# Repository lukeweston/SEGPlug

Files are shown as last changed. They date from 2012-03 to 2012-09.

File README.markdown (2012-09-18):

**SEGPlug: A single-channel, single-phase, portable, wireless mesh-networked smart energy data acquisition and control appliance**

Design by Luke Weston, 2011-2012
(c) Luke Weston 2011-2012

This hardware design is released to you under the CERN Open Hardware License: http://ohwr.org/cernohl

The Smart Energy Groups SEGPlug is a small, visually unintrusive and portable device which plugs in to a domestic mains power outlet or cable and plugs into a mains-powered
load device. It is (with a small hardware reconfiguration) compatible with worldwide mains power grids, at 110-240VAC and 50-60 Hz. This "Internet of Things" device collects
data from its sensors and data acquisition circuits and transmits this data to a distributed network and ultimately to the Internet and receives commands from a distributed
network and/or the Internet and responds to such commands, for example by switching its onboard power relay on or off. 

SEGPlug acquires the voltage waveform across the load device(s) and the current waveform being consumed by the load device(s) and calculates instantaneous power draw as well
as energy consumption integrated across some period of time, and complex AC power characteristics such as phase angle, reactive power and power factor.

SEGPlug also incorporates a relay allowing the power supply to the load device to be completely switched off and switched on at the command of the device's (very low power)
internal microcontroller.

SEGPlug is powered from the mains power supply which it is plugged into - no additional power supplies or cables are required, everything is integrated into one clean and
simple plug-in cable.

SEGPlug sends and receives data and commands over a wireless radio mesh network, back to a gateway device which bridges the wireless mesh network onto an existing local area
network which is connected to the Internet - over ethernet, and/or standard IEEE 802.11 wireless networking (Wi-Fi), or 3G or similar cellular networks.

To ensure flexible compatibility with worldwide radiofrequency spectrum licensing and regulations and the device's local electromagnetic environment (with respect to spectrum
congestion, interference, or electromagnetic shielding, reflection or attenuation by nearby structures materials in the environment) SEGPlug's radio communications are handled
on a replaceable daughterboard which can be replaced and swapped with different boards or modules employing different communications frequencies or protocols.

My in-house daughterboard design based around the Atmel ATmega128RFA1 radio/microcontroller can be used, thus providing connectivity over IPv6 / 6LoWPAN etc, as well as
ZigBee. Alternatively, a commercial off-the-shelf product such as a Digi/MaxStream XBee module can be used, operating in the 2.4 GHz or 900 MHz spectra with the ZigBee or
DigiMesh protocols (which are, at their lower layers, also built on the 802.15.4 standard.) A daughterboard based around a sub-gigahertz radio device such as the Texas
Instruments CC1101 IC, operating in the 315/433/868/915 MHz bands can also be used, either in the form of a bespoke RF transceiver from us or a COTS device such as the
Seeed RFBee module.

SEGPlug also incorporates a temperature sensor, for measurement of the temperature in the local environment, a light sensor for sensing of the ambient light level, and support
for an optional PIR motion sensor for the detection of motion and an automated response - for example, turning on the room lights and/or reporting a message to the network.

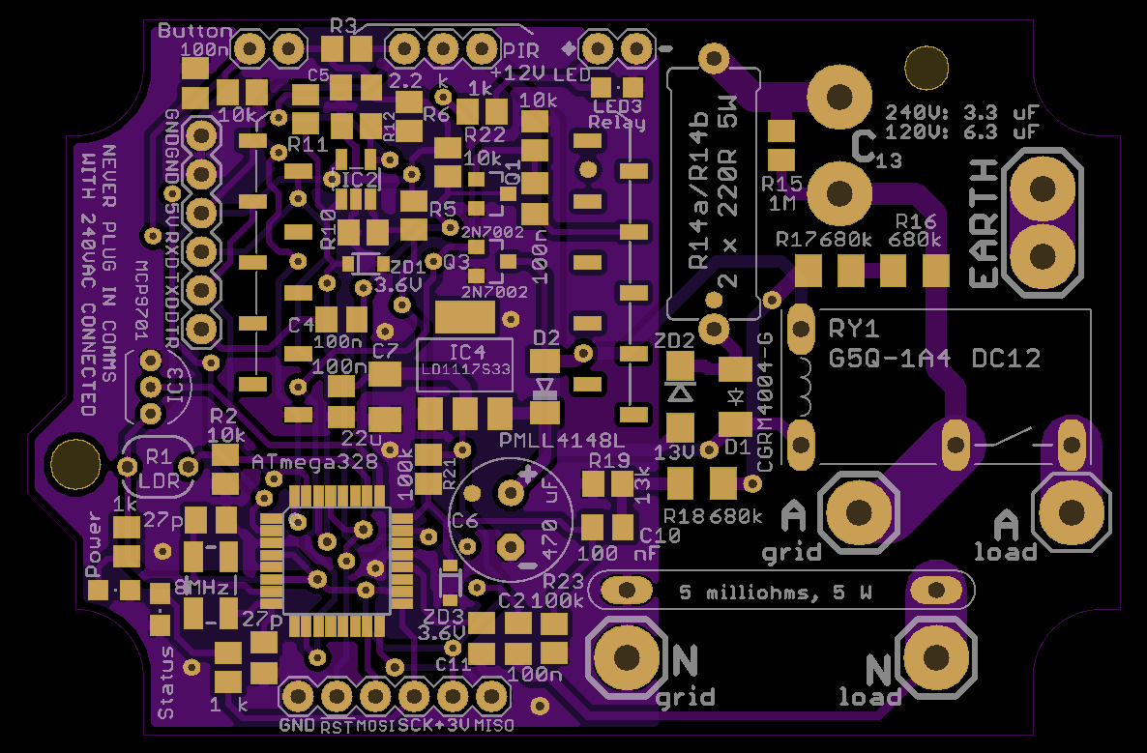
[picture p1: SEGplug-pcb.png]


*Engineering notes for hardware developers, prototype testers, and early adopters:*

This device uses a non-isolated, transformerless mains power supply, with the mains active serving as the local DC ground. What this means is that all parts of the device,
including the microcontroller, XBee module, temperature sensor, and the light and PIR sensors if they're connected, are at mains potential when the device is plugged into the
mains, and all components represent an electric shock hazard. Do not not poke around with this device while it is powered up, with the device not within an earthed enclosure,
or a double-insulated plastic enclosure, unless you know exactly what you're doing.

Also, DO NOT plug the device into any kind of FTDI cable, ISP programmer or any other serial communications interface or programming interface while it is plugged into the
mains. If you do, this will connect your computer's local DC ground to the 240VAC active, and your computer will be destroyed and will probably explode or something, as well
as presenting an electric shock hazard. So don't do it.

It's OK to plug those kinds of interfaces in for programming, obviously, just make damned sure that the mains is unplugged first.

There's nothing "wrong" with a transformerless power supply, though, as long as you understand what it is and what its characteristics are. You'll find very much the same kind
of circuit inside a commercial "kill-a-watt" device, or any similar product. As long as the device does not need to have any cables for data communications out to a computer
or another device, it works absolutely fine. In fact, using this kind of circuit is the only way you're going to keep the size, weight and cost of the device down so that it
is competitive with those kinds of similar commercial products.

The transformerless power supply uses a relatively large cap (2.2 uF) because it needs to supply a relatively large amount of current (about 80 mA) at peak times in order to
reliably run the XBee module (which draws about 50 mA by itself) as well as the relay and AVR without rebooting or crashing the AVR whenever there is a momentary spike in
current draw, whenever the XBee starts transmitting or something like that.

High current means low capacitive reactance which means relatively big capacitor.

Commercial RF modules with relatively high power consumption, such as the Digi/Maxstream "XBee Pro" are unsupported with this system due to power supply constraints in this
design variant and probably won't work reliably, although the standard, lower-power Digi/MaxStream XBee modules are supported. Basically, when using commercial third-party
RF communications modules, the maximum device current consumption during transmission should not exceed 50 mA at 3.3 volts.

It would straightforward to design a safe, optically-isolated plug-in serial cable interface for your computer if something like that was required... but at this point in
time, no such device exists and plugging the unit into your computer (unless the mains is disconnected) is a big no-no.

The maximum power rating of the unit is 10 A at 240 VAC. Do not exceed this limit.

This device is designed for use with 240 VAC mains only. Do not use in a country with a 120 VAC mains supply. It should be possible to change the value of the
capacitive reactance in the mains neutral so that it is OK with 120 VAC operation (which probably means changing the 2.2 uF capacitor to about double its capacitance), but at
the present time this has not been tested and is not supported at all.

The control pushbutton must be rated for mains use. If there is not sufficient electrical isolation between the switch contacts and the plastic switch actuator, an electric
shock hazard may exist during use of the button.

In order to prevent electric shock, fire, explosion, death, etc, careful quality control is required if you're assembling this unit from a kit yourself. Solder everything
carefully, and check that you've got the components oriented correctly with the right kinds of components in the right places.

The 470 uF electrolytic capacitor must be installed with the correct polarity, and the AVR microcontroller must be soldered in with the right orientation.
The 5 different diodes in the circuit all must be installed with the correct polarity and with the right type of diode used in the right spot on the PCB.

**Microcontroller notes, and wireless programming**:

The AVR (which is essentially an Arduino, if it is programmed with an Arduino bootloader) can be reprogrammed remotely via the XBee, if it is programmed with the Arduino
bootloader. Follow the directions here:

http://www.ladyada.net/make/xbee/arduino.html

Note that the hardware configuration at the remote end is already implemented on the board... the XBee modules just need to be configured appropriately and the XBee module
at the host end appropriately connected to a UART interface to the PC.

Note that the AVR is clocked from an 8 MHz crystal and it is running at 3.3V. Therefore, the Arduino IDE must be told that the target device is a 3.3V 8 MHz Arduino prior to
programming.

It is perfectly fine to perform XBee wireless communications and XBee program downloads while the device is plugged into the mains power supply, of course.

During "wired" flashing or programming (either with the ISP programmer or with a FTDI serial cable), the *XBee module must be removed from its socket*.

**Temperature sensor**:

A substantially cheaper Microchip MCP9701 temperature sensor IC with a linear analog output is used to replace the relatively expensive DS18B20 temperature sensor.

**Measurement resolution**:

The power measurement resolution or "granularity" should be about 2.5W per LSB, when operating from 230VAC.

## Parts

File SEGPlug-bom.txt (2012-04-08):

SEGPlug Bill of Materials
							
Qty		Component IDs		Value			Packaging			Digi-Key SKU		Unit Price (USD)	Subtotal	Notes

Resistors
5		R2, R3, R4, R9, R13	10 k			0805 SMD			311-10KARCT-ND		0.0170			0.0850	
4		R5, R10, R21, R23	100 k 1%		0805 SMD			311-100KCRCT-ND		0.0200			0.0800	
2		R6, R12			2.2 k 1%		0805 SMD			311-2.20KCRCT-ND	0.0200			0.0400	
3		R7, R8, R22		1 k			0805 SMD			311-1.0KARCT-ND		0.0170			0.0510	
2		R11, R19		13 k 1%			0805 SMD			RMCF0805FT13K0CT-ND	0.0400			0.0800	
1		R15			1 M			0805 SMD			311-1.0MARCT-ND		0.0170			0.0170	
1		R1			CdS LDR			Small through-hole LDR		PDV-P8103-ND		0.8000			0.8000	
2		R14a, R14b		220R 5W			Large ceramic through-hole	UB5C-220-ND		0.8400			1.6800	
3		R16, R17, R18		680k 1%			1206 SMD			311-680KFRCT-ND		0.0320			0.0960	
1		R20			5 milliohms 5W		Through-hole			989-1096-ND		1.0000			1.0000	
							
Capacitors							
1		C13			3.3 uF 250VAC		Large through-hole		495-4138-ND		2.9300			2.9300	
8		C1-C5, C10, C11, C12	100 nF, 50V		0805 SMD ceramic		311-1361-1-ND		0.0310			0.2480	
1		C6			470 uF, 16V		3.5 mm pitch, 8mm dia.		565-1678-ND		0.4100			0.4100	
1		C7			22 uF, 50V		1206 SMD ceramic		490-1824-1-ND		0.3600			0.3600	
2		C8, C9			27 pF, 50V		0805 SMD ceramic		311-1104-1-ND		0.0620			0.1240	
							
Semiconductors							
1		D1			CGRM4004-G		SOD-123				641-1329-1-ND		0.4100			0.4100	
1		D2			PMLL4148		Mini-MELF			568-1749-1-ND		0.1200			0.1200	
2		ZD1, ZD3		3.6 V Zener diode	SOD-323				568-8044-1-ND		0.2700			0.5400	
1		ZD2			13 V Zener diode	DO-214AC			3SMAJ5928B-TPMSCT-ND	0.5800			0.5800	
1		LED1			Red LED (Power)		0805 SMD			475-1278-1-ND		0.1100			0.1100	
1		LED2			Green LED (Relay)	0805 SMD			754-1131-1-ND		0.1600			0.1600	
1		LED3			Yellow LED (Status)	0805 SMD			754-1135-1-ND		0.1600			0.1600	
2		Q1, Q3			2N7002 MOSFET		SOT23				568-5818-1-ND		0.1400			0.2800	
1		Q2			8 MHz crystal		5mm x 3mm SMD			535-9720-1-ND		1.4300			1.4300	
1		IC2			OPA340NA		SOT-23 5-pin			OPA340NACT-ND		2.9300			2.9300	
1		IC1			MCP9701			TO-92				MCP9701A-E/TO-ND	0.3400			0.3400	
1		IC4			LD1117S33		SOT-223				497-1241-1-ND		0.4800			0.4800	
1		IC5			ATmega328		TQFP32				ATMEGA328-AU-ND		3.8300			3.8300	
1		IC1			XBee Module		N/A				
							
Miscellaneous							
1		RY1			Relay							Z223-ND			3.1800			3.1800	
2		N/A			2.0 mm 10-pin header socket 				S5751-10-ND		1.1100			2.2200	
2		J2, J4			6-pin 0.1" male header					3M9451-ND		0.3300			0.6600	
							
																	Total:	25.4310
																(Excludes XBee and PCBs and shipping.)

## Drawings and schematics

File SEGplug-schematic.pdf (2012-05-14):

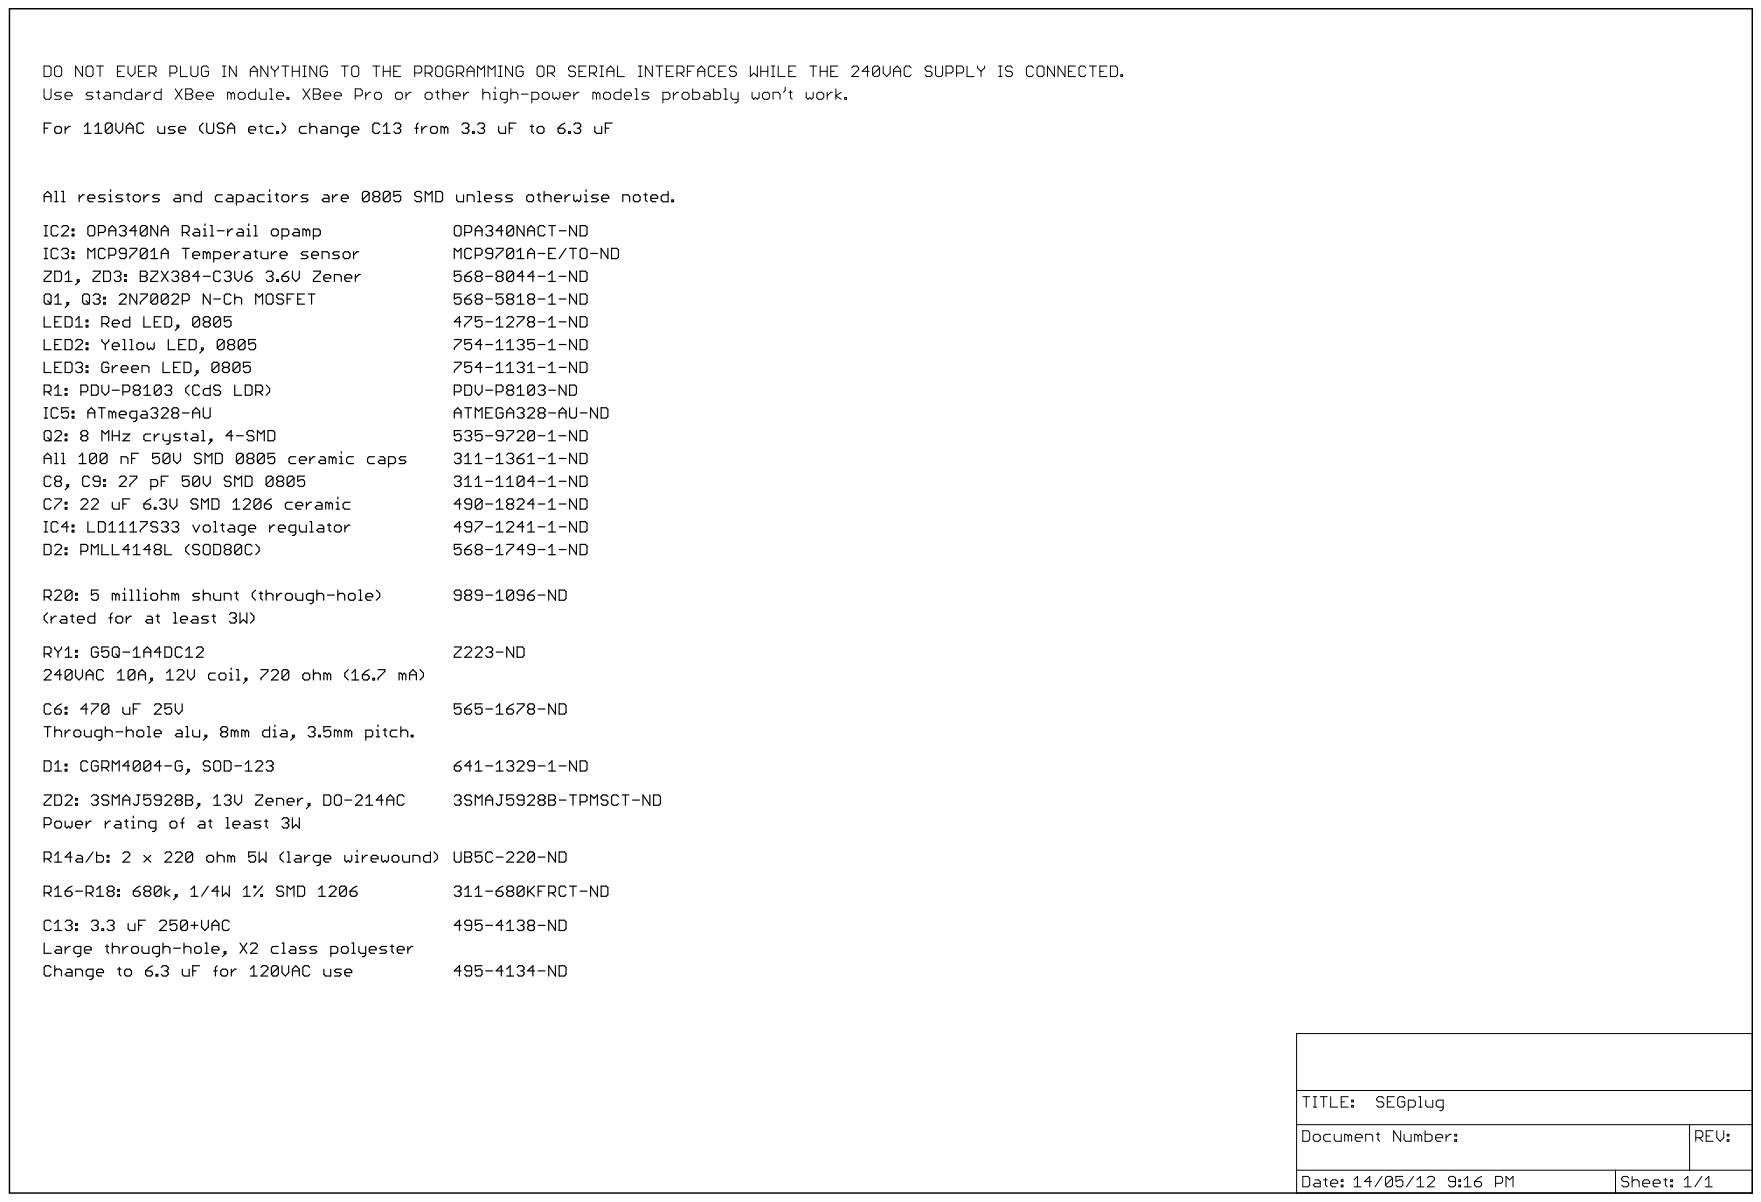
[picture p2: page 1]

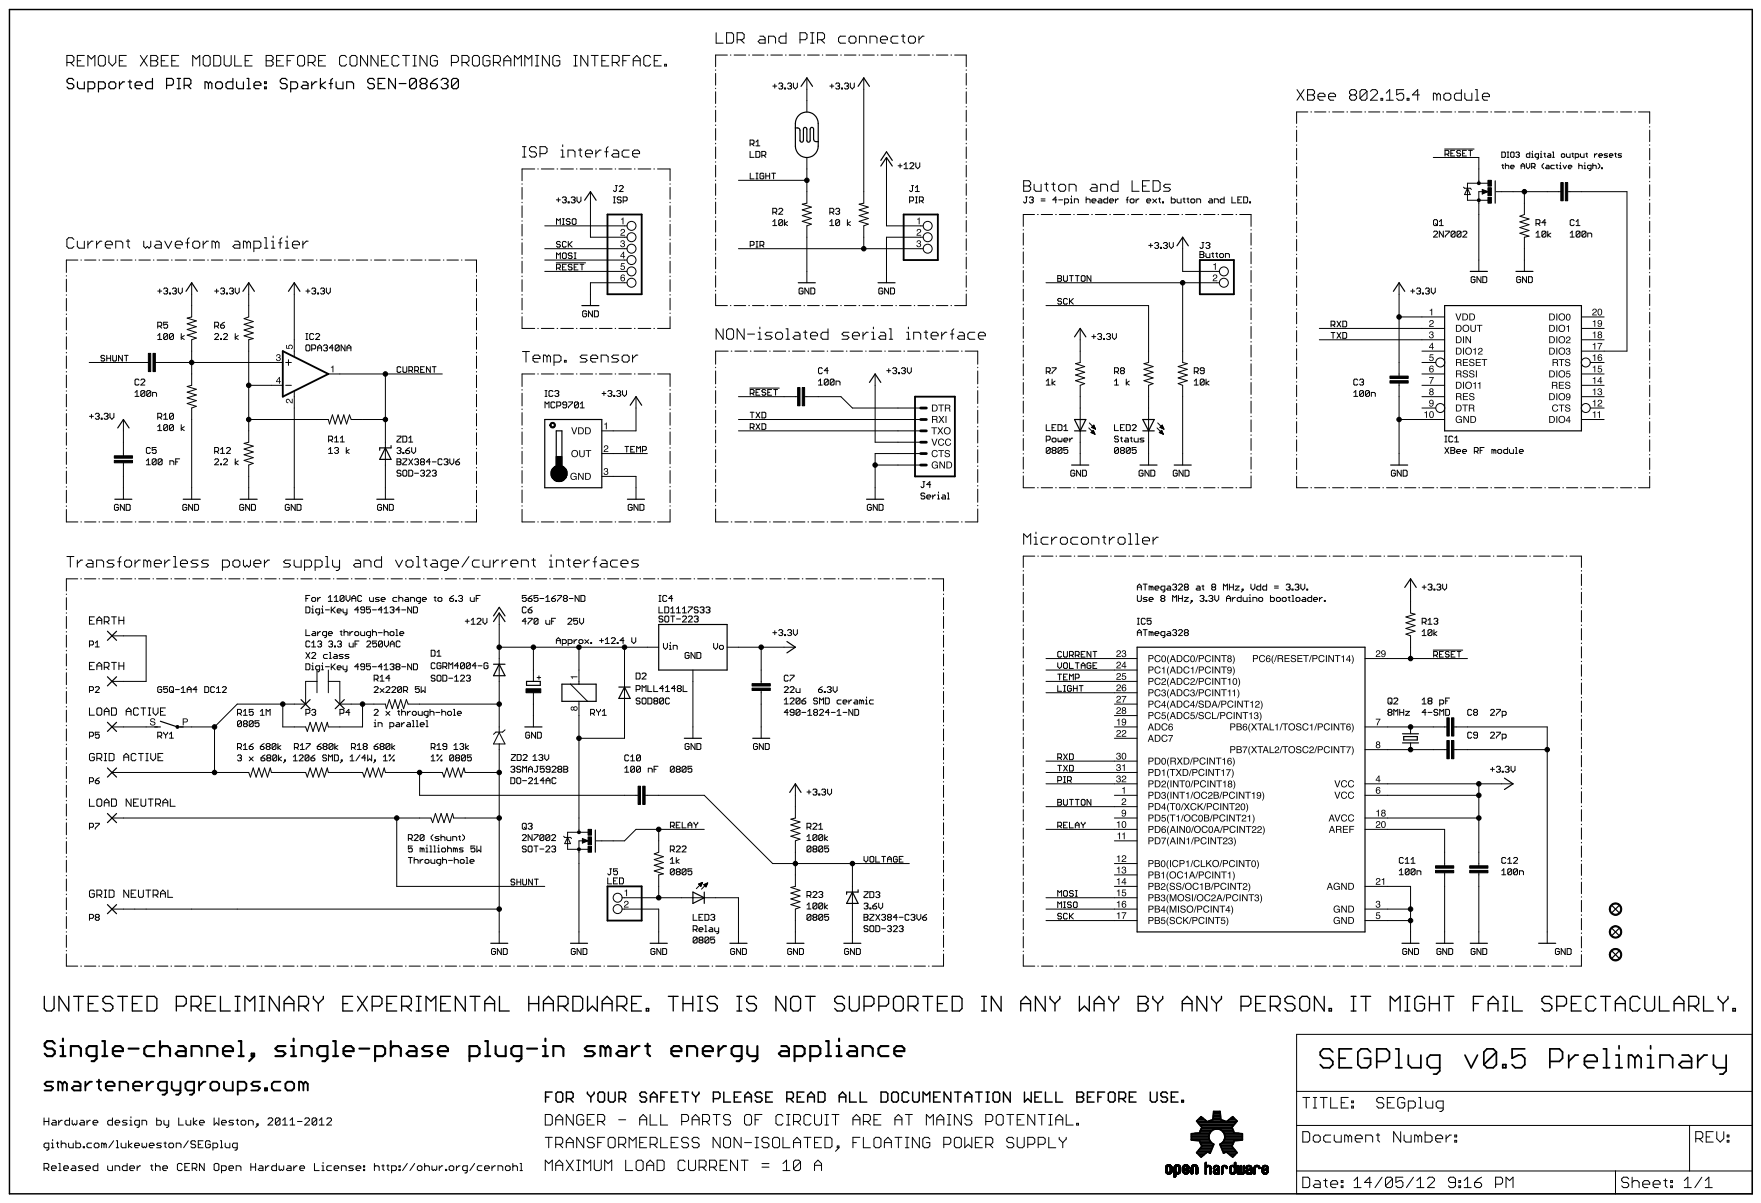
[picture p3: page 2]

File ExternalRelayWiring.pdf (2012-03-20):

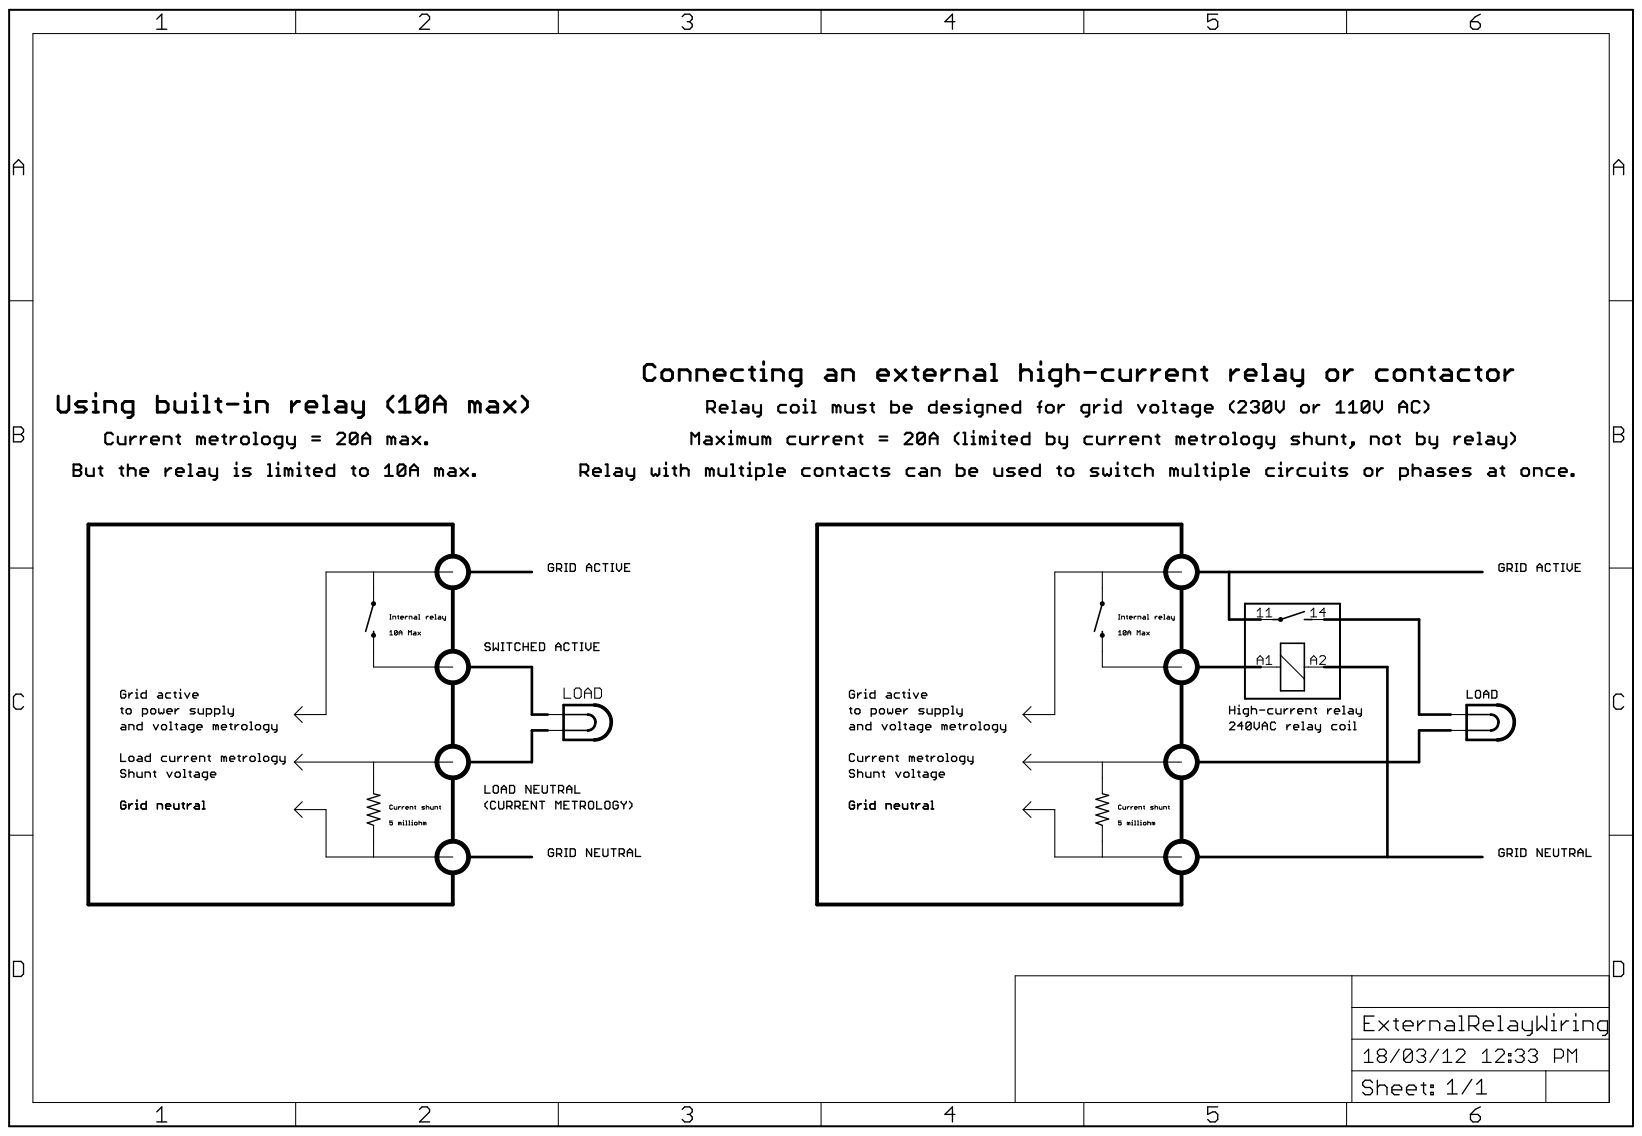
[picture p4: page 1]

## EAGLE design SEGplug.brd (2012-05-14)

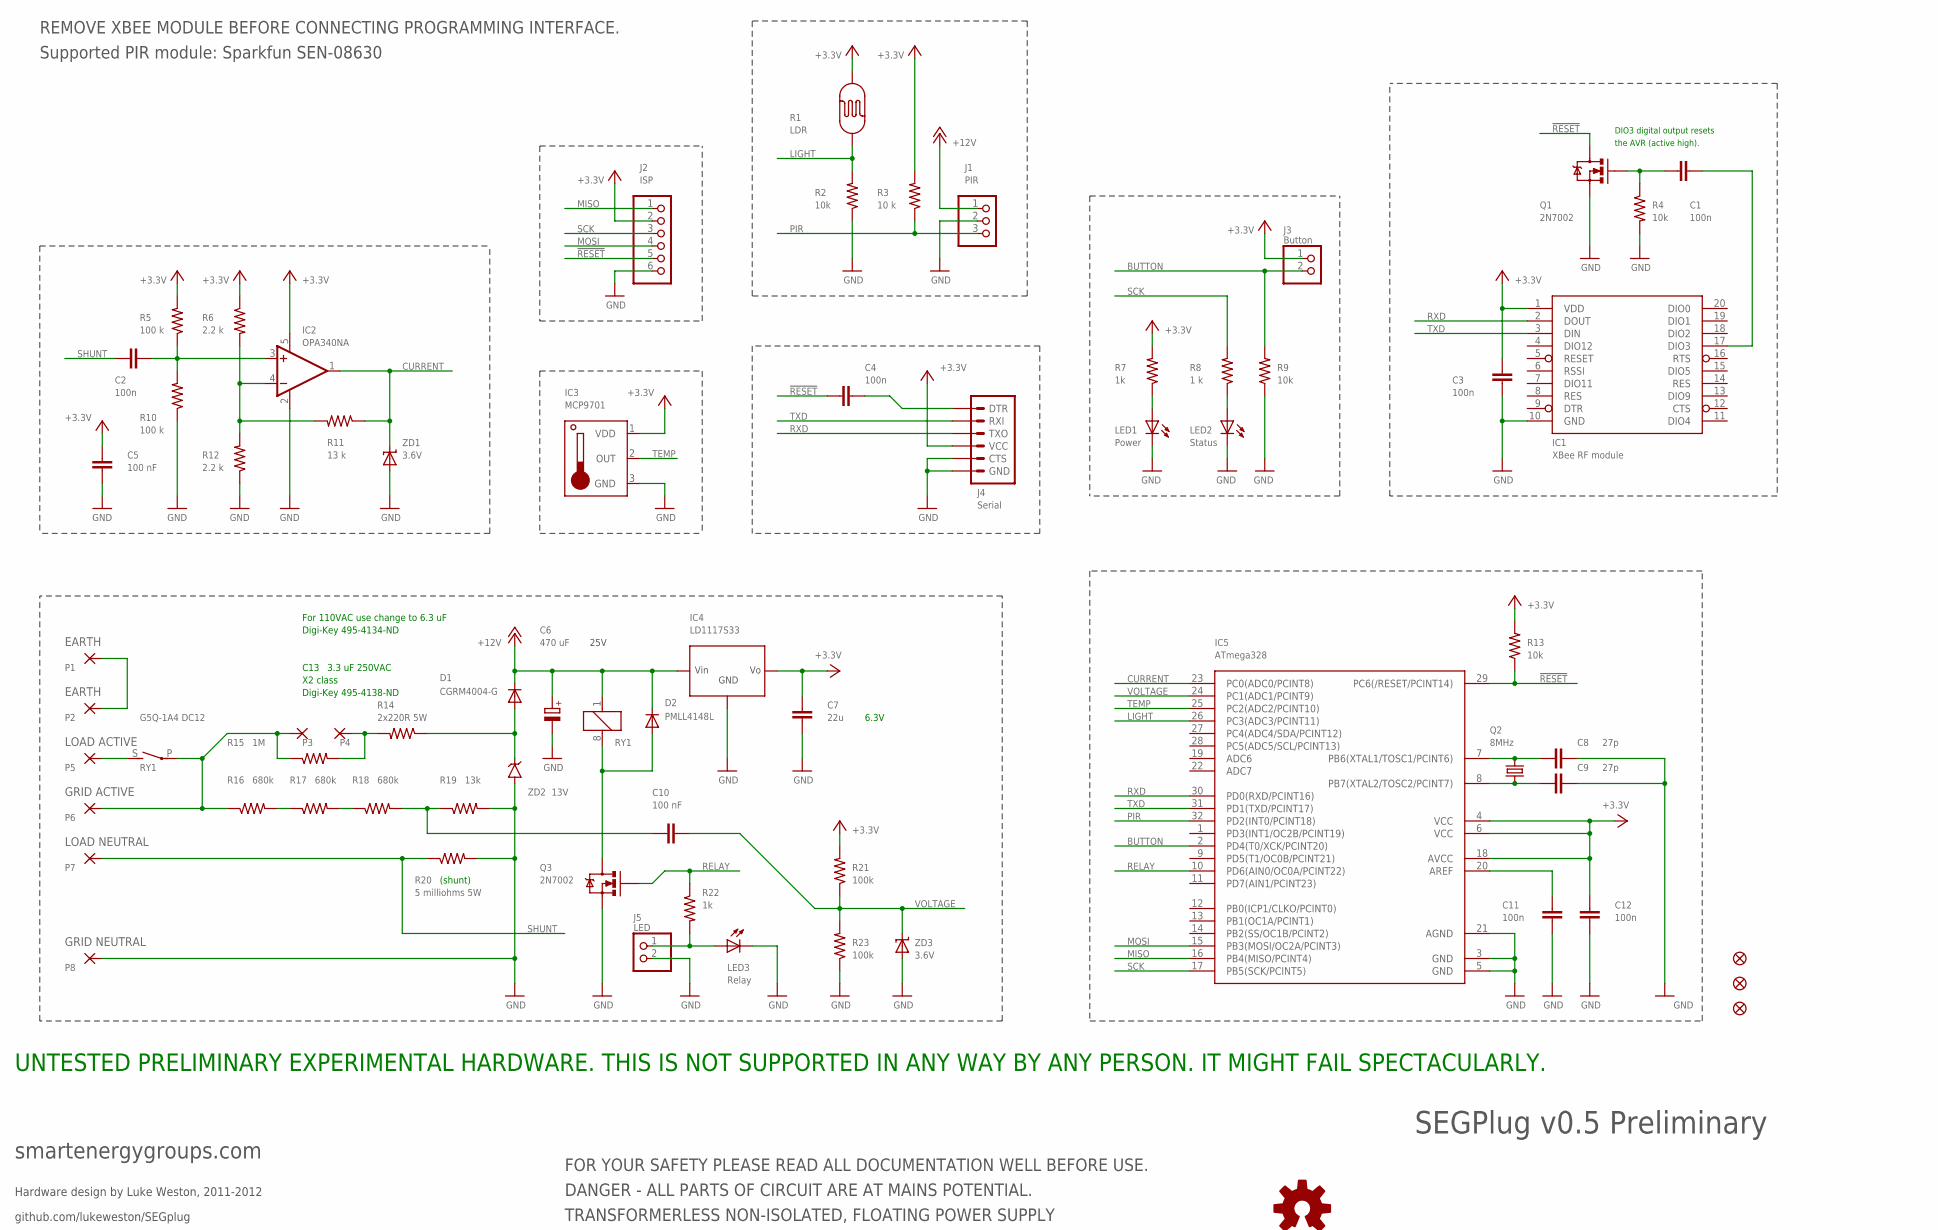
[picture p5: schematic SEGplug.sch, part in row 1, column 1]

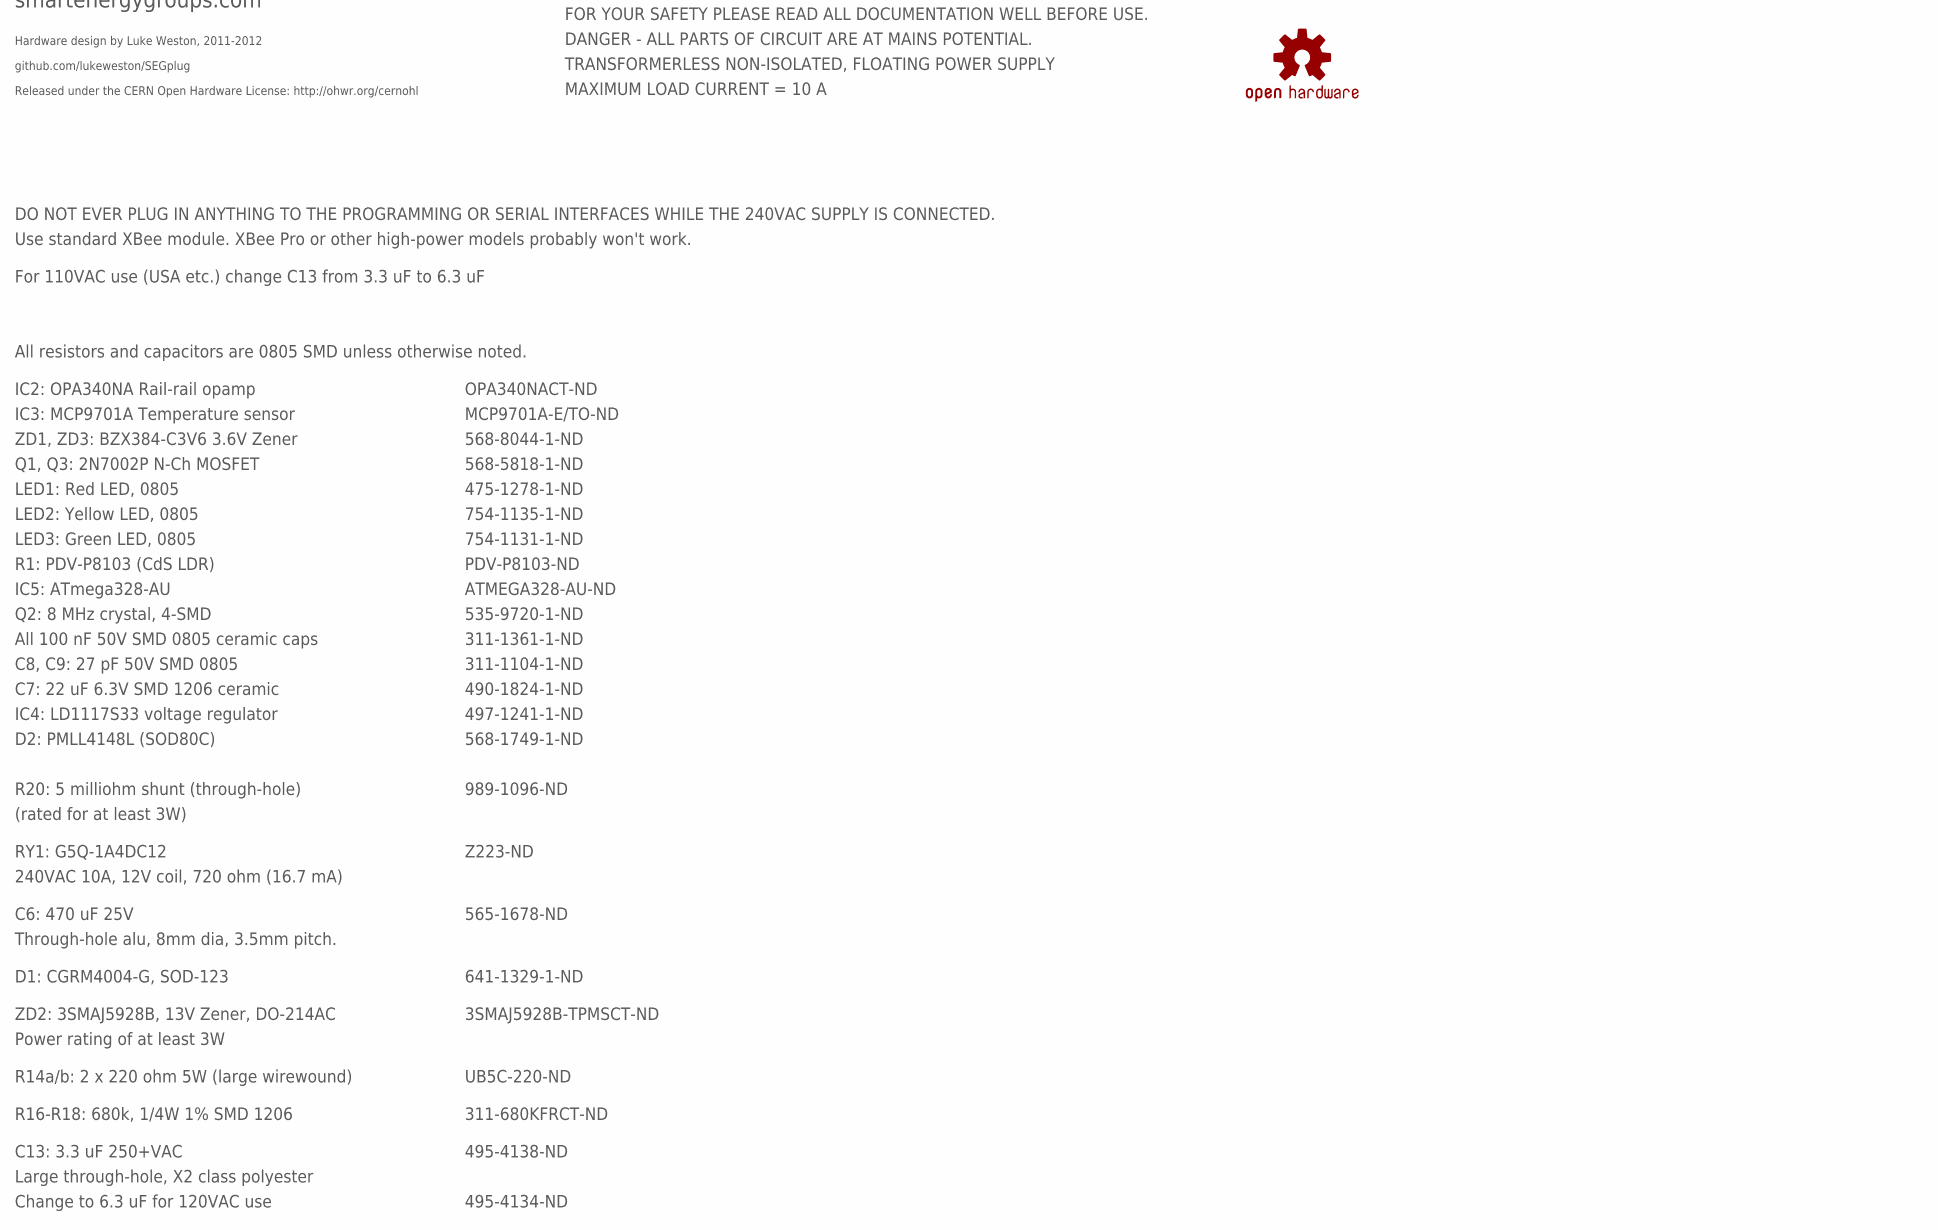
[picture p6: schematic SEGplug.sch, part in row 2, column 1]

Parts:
C1, C2, C3, C4, C11, C12: 100n; C0805K
C5, C10: 100 nF; C0805K
C6: 470 uF; E3,5-8
C7: 22u; C1206K
C8, C9: 27p; C0805K
D1: CGRM4004-G; SOD-123_MINI-SMA
D2: PMLL4148L; MINIMELF
IC1: XBee RF module; XBEE-SMD
IC2: OPA340NA; SOT23-5
IC3: MCP9701; TO92
IC4: LD1117S33; SOT223
IC5: ATmega328; TQFP32-08
J1: PIR; 1X03
J2: ISP; 1X06
J3: Button; 1X02
J4: Serial; 1X06
J5: LED; 1X02
JP1, JP2, JP3: FIDUCIAL1X2; FIDUCIAL-1X2
LED1: Power; CHIPLED_0805
LED2: Status; CHIPLED_0805
LED3: Relay; CHIPLED_0805
P1, P2: EARTH; 4,16O1,6
P3, P4: CAP; 4,16O1,6
P5: LOAD ACTIVE; 4,16O1,6
P6: GRID ACTIVE; 4,16O1,6
P7: LOAD NEUTRAL; 4,16O1,6
P8: GRID NEUTRAL; 4,16O1,6
Q1, Q3: 2N7002; SOT23-3
Q2: 8MHz; CRYSTAL-SMD-5X3
R1: LDR; PHOTOCELL
R2, R4, R9, R13: 10k; M0805
R3: 10 k; M0805
R5, R10: 100 k; M0805
R6, R12: 2.2 k; M0805
R7, R22: 1k; M0805
R8: 1 k; M0805
R11: 13 k; M0805
R14: 2x220R 5W; 0617/17
R15: 1M; M0805
R16, R17, R18: 680k; M1206
R19: 13k; M0805
R20: 5 milliohms 5W; RSENSE2_RSENSE
R21, R23: 100k; M0805
RY1: G5Q-1A4 DC12; G6C-1117P
U$: OSHW-LOGOS; OSHW-LOGO-S
ZD1, ZD3: 3.6V; SOD-323
ZD2: 13V; DO214AC

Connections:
!RESET: C4.2, IC5.29 (PC6(/RESET/PCINT14)), J2.5, Q1.3 (D), R13.1
+3V3: C3.1, C5.1, C7.1, C12.1, IC1.1 (VDD), IC2.5 (V+), IC3.1 (VDD), IC4.2 (VOUT), IC5.4 (VCC), IC5.6 (VCC), IC5.18 (AVCC), J2.2, J3.1, J4.4 (VCC), R1.2, R3.2, R5.2, R6.1, R7.2, R13.2, R21.2
+12V: C6.+, D1.C, D2.C, IC4.3 (VIN), J1.1, RY1.1
BUTTON: IC5.2 (PD4(T0/XCK/PCINT20)), J3.2, R9.2
CURRENT: IC2.1 (OUT), IC5.23 (PC0(ADC0/PCINT8)), R11.1, ZD1.1 (C)
DIO3: C1.1, IC1.17 (DIO3)
GND: C3.2, C5.2, C6.-, C7.2, C8.2, C9.2, C11.2, C12.2, IC1.10 (GND), IC2.2 (V-), IC3.3 (GND), IC4.1 (GND), IC5.3 (GND), IC5.5 (GND), IC5.21 (AGND), J1.2, J2.6, J4.5 (CTS), J4.6 (GND), J5.2, LED1.C, LED2.C, LED3.C, P8.1, Q1.2 (S), Q3.2 (S), R2.1, R4.2, R9.1, R10.1, R12.1, R19.2, R20.P$2 (2), R23.1, ZD1.2 (A), ZD2.A, ZD3.2 (A)
LIGHT: IC5.26 (PC3(ADC3/PCINT11)), R1.1, R2.2
MISO: IC5.16 (PB4(MISO/PCINT4)), J2.1
MOSI: IC5.15 (PB3(MOSI/OC2A/PCINT3)), J2.4
unnamed: LED1.A, R7.1
unnamed: P3.1, P6.1, R15.1, R16.1, RY1.P
unnamed: R17.2, R18.1
unnamed: D2.A, Q3.3 (D), RY1.8 (2)
unnamed: J5.1, LED3.A, R22.2
unnamed: P5.1, RY1.S
unnamed: C11.1, IC5.20 (AREF)
unnamed: P1.1, P2.1
unnamed: C8.1, IC5.7 (PB6(XTAL1/TOSC1/PCINT6)), Q2.3 (2)
unnamed: C9.1, IC5.8 (PB7(XTAL2/TOSC2/PCINT7)), Q2.1
unnamed: LED2.A, R8.1
unnamed: C1.2, Q1.1 (G), R4.1
unnamed: P4.1, R14.2, R15.2
unnamed: D1.A, R14.1, ZD2.C
unnamed: C10.2, R18.2, R19.1
unnamed: C4.1, J4.1 (DTR)
unnamed: R16.2, R17.1
unnamed: IC2.4 (-IN), R6.2, R11.2, R12.2
unnamed: C2.1, IC2.3 (+IN), R5.1, R10.2
PIR: IC5.32 (PD2(INT0/PCINT18)), J1.3, R3.1
RELAY: IC5.10 (PD6(AIN0/OC0A/PCINT22)), Q3.1 (G), R22.1
RXD: IC1.2 (DOUT), IC5.30 (PD0(RXD/PCINT16)), J4.3 (TXO)
SCK: IC5.17 (PB5(SCK/PCINT5)), J2.3, R8.2
SHUNT: C2.2, P7.1, R20.P$1 (1)
TEMP: IC3.2 (OUT), IC5.25 (PC2(ADC2/PCINT10))
TXD: IC1.3 (DIN), IC5.31 (PD1(TXD/PCINT17)), J4.2 (RXI)
VOLTAGE: C10.1, IC5.24 (PC1(ADC1/PCINT9)), R21.1, R23.2, ZD3.1 (C)

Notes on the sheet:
DANGER - ALL PARTS OF CIRCUIT ARE AT MAINS POTENTIAL.
DO NOT EVER PLUG IN ANYTHING TO THE PROGRAMMING OR SERIAL INTERFACES WHILE THE 240VAC SUPPLY IS CONNECTED.
MAXIMUM LOAD CURRENT = 10 A
REMOVE XBEE MODULE BEFORE CONNECTING PROGRAMMING INTERFACE.
Hardware design by Luke Weston, 2011-2012
Released under the CERN Open Hardware License: http://ohwr.org/cernohl
Use standard XBee module. XBee Pro or other high-power models probably won't work.
DIO3 digital output resets
SEGPlug v0.5 Preliminary
smartenergygroups.com
UNTESTED PRELIMINARY EXPERIMENTAL HARDWARE. THIS IS NOT SUPPORTED IN ANY WAY BY ANY PERSON. IT MIGHT FAIL SPECTACULARLY.
github.com/lukeweston/SEGplug
6.3V
For 110VAC use (USA etc.) change C13 from 3.3 uF to 6.3 uF
240VAC 10A, 12V coil, 720 ohm (16.7 mA)
TRANSFORMERLESS NON-ISOLATED, FLOATING POWER SUPPLY
Supported PIR module: Sparkfun SEN-08630
FOR YOUR SAFETY PLEASE READ ALL DOCUMENTATION WELL BEFORE USE.
25V
3.3 uF 250VAC
X2 class
(shunt)
C13
the AVR (active high).
All resistors and capacitors are 0805 SMD unless otherwise noted.
IC2: OPA340NA Rail-rail opamp
ZD1, ZD3: BZX384-C3V6 3.6V Zener
IC3: MCP9701A Temperature sensor
R1: PDV-P8103 (CdS LDR)
Q1, Q3: 2N7002P N-Ch MOSFET
LED3: Green LED, 0805
LED1: Red LED, 0805
LED2: Yellow LED, 0805
OPA340NACT-ND
MCP9701A-E/TO-ND
568-8044-1-ND
568-5818-1-ND
475-1278-1-ND
754-1135-1-ND
754-1131-1-ND

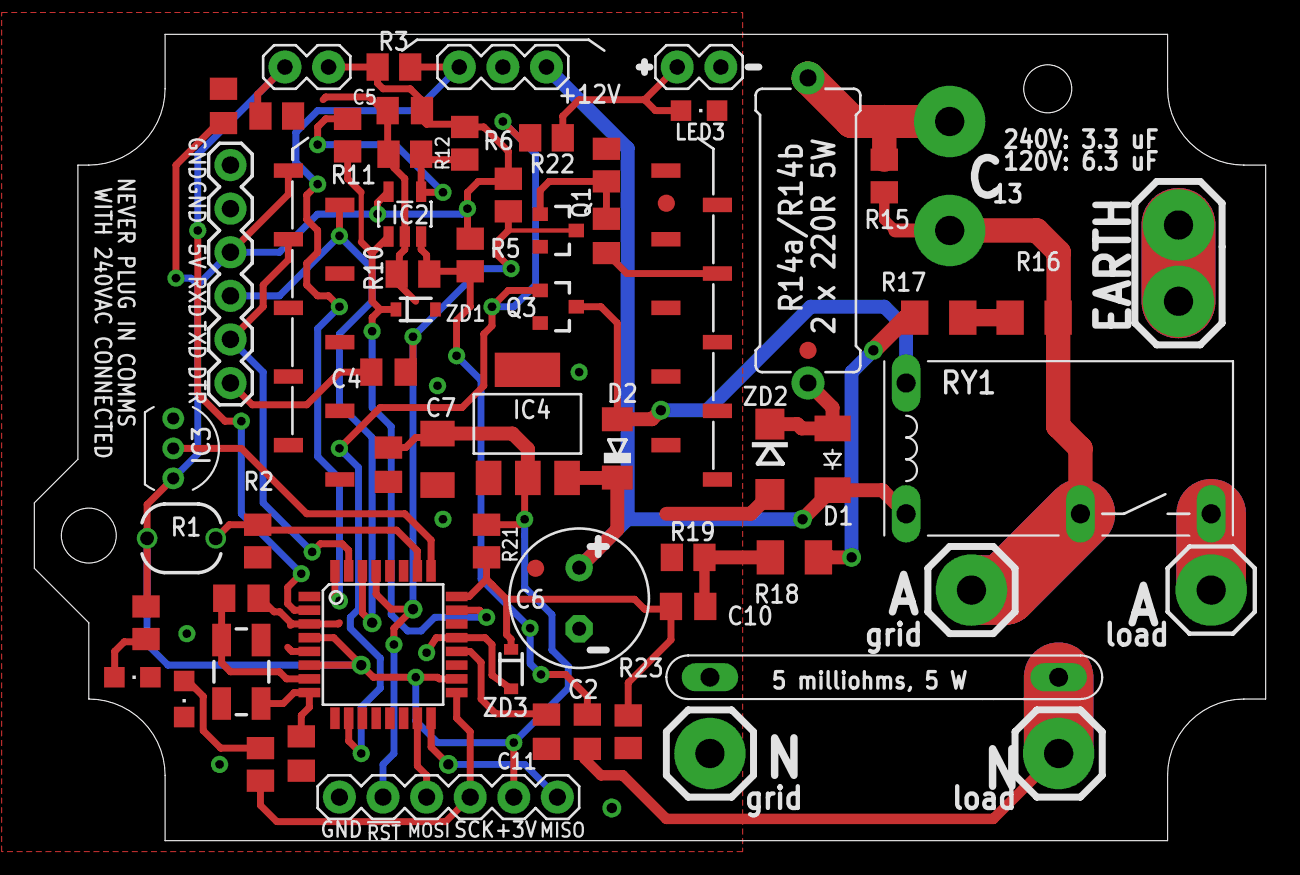
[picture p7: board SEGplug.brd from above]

Board: 2 copper layers, 71.8 x 47.0 mm, 69 parts (1 on the bottom side), 37 nets.

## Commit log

2012-02-09 partially completed new revised design
    [SEGplug.brd, SEGplug.sch]
2012-03-07 Finished new design
    [SEGplug.brd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]
